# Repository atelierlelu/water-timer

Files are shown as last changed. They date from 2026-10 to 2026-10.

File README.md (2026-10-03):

# Water timer

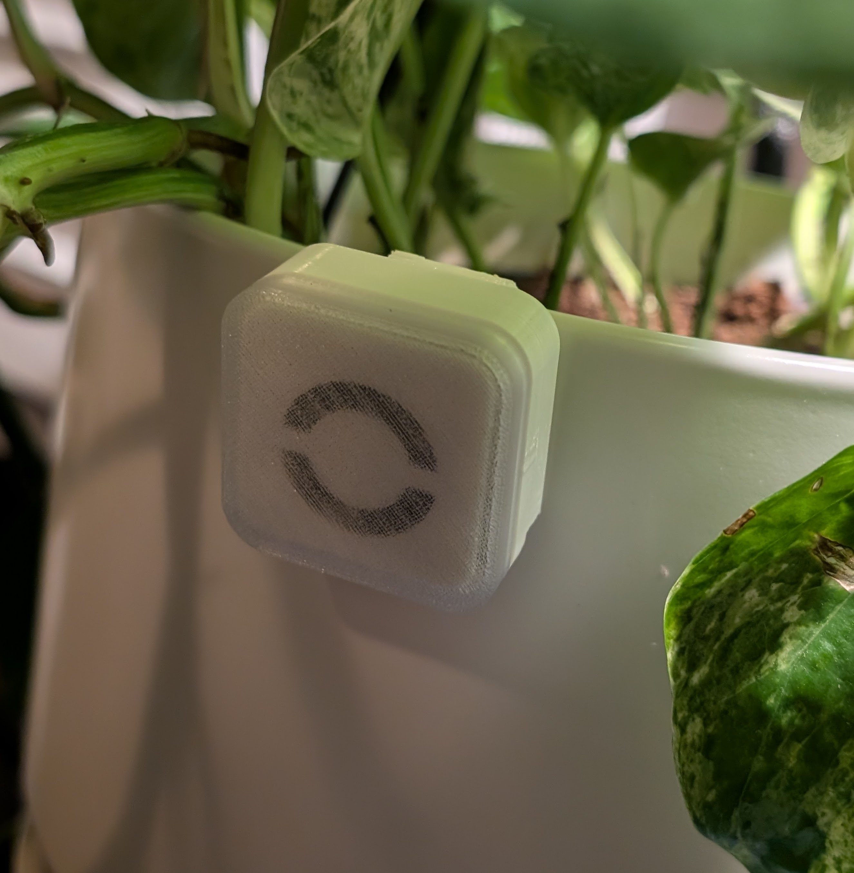
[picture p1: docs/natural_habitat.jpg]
Water timer clipped to a plant pot


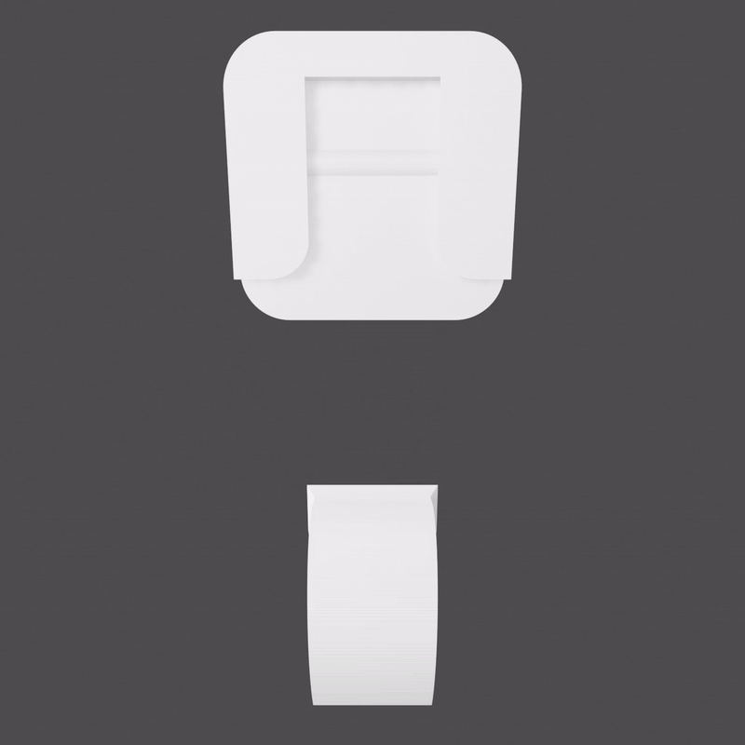
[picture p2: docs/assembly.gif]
Assembly of the water timer


CC-BY-4.0. Copyright (c) 2026 Atelier Lelu.

A small device to remind you to water a plant. Battery powered but it lasts years. That's it.

An article about the project is at <https://lelu.uk/water-timer/>.

## How to use

Once assembled, enter setup mode to configure how often it waits before blinks (1, 3 or 7 days) by long pressing the top right button for 1.5 seconds. When you release you can cycle through durations by pressing the centre button - green LEDs will blink once (for 1 day), 3 times (for 3 days) or a long blink for 7 days. It auto saves after 10 seconds.
Once the 1/3/7 days have passed, the device will blink green every minute (twice) to remind you to water the plant. Once watered press the centre button once, green LEDs flash as acknowledgement and that's it.
When the battery is low the red light will flash on button presses of when watering is due - but it should take years before you reach that point.

## In this repository

| Path | What it is |
| --- | --- |
| `enclosure/print/` | STLs to print: back, front, light mask, hook |
| `enclosure/source/` | Matching STEP files, for editing |
| `hardware/` | KiCad project, plus the JLCPCB gerbers, BOM and placement file. The schematic is [hardware/schematic.pdf](hardware/schematic.pdf) |
| `firmware/` | Plant-timer firmware, flash and test tools |
| `docs/` | Documentation |

## Make one

Print the four STLs, order the board, solder the coin-cell holder, flash the firmware, then close the case. The steps, including which jumper to close for a cell-powered timer, are in [docs/build.md](docs/build.md).

Flash before the board goes into the case. From `firmware/`:

```bash
make
make flash
```

Leave the option bytes alone. Programmer wiring and the button and LED behaviour are in [firmware/README.md](firmware/README.md).

Assembly, in order: hook, cell, board on the alignment pins, light mask, front. There are no screws. The picture is [docs/exploded.png](docs/exploded.png).

## License

Three licenses, one per kind of file. See [LICENSE.md](LICENSE.md). Hardware is CERN-OHL-P-2.0, firmware is MIT, and the documents are CC-BY-4.0. The ST files under `firmware/Drivers/` stay BSD-3-Clause.

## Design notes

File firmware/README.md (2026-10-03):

# water timer firmware (STM32L011F4, rev B)

CLI firmware for the rev B **STM32L011F4P6** board (TSSOP20). CubeMX 6.17 generated the HAL project as **EWARM only**; this tree adds a GCC `Makefile` and linker script so you can build, flash, and log from the command line.

The current image is the **plant timer** (`Core/Src/app.c`): Stop + LSI RTC, watered / view / setup on the two buttons, EEPROM interval, low-battery overlay. Waiting uses the EEPROM 1/3/7 day. How to force a one-minute due on the bench is in [Bench test](#bench-test).

## Everyday use

NRST is wired to the ST-LINK. `make flash` connects under reset, so the chip can be in Stop.

```bash
make
make flash
make picocom        # live UART on /dev/ttyACM0 (Ctrl-A Ctrl-X to quit)
```

Leave the option bytes alone. Rev B pulls BOOT0 down, so a new chip boots main flash. `make optbytes` is not part of programming this board.

A plain `st-info` while the core is in Stop can show `chipid 0x000`. That is the debug clock gated, not a dead chip. Connect under reset, or wait until the core is in Run.

The core stays in Run for **10 s after reset** with both LEDs blinking (`never_remove_swd_boot_window()` in `main.c`). **Do not remove, shorten, or move it.** It is the visible sign that the new image started, and a second way to attach if reset connect fails. After the window the plant timer starts and enters Stop.

SETUP (long-press the small button, solid red) also holds Run. The 10 s idle timer leaves SETUP and enters Stop. If a write is going without reset held, tap the big button about every 5 s until flash says verified, or a half-erased image comes back as UART garbage.

If `make flash` does not attach:

```bash
make catchflash              # retry SWD for 90 s
make catchflash CATCH_SECS=30
```

Short non-interactive capture: `make serial`. SWD RTT (`make log`) still works but halts the core; prefer UART.

## First fresh board

Factory option bytes are already the right ones. Do not run `make optbytes`.

1. Programmer first: an ST-LINK appears as `0483:374b` on USB, with UART on `/dev/ttyACM0`. Cube Programmer should show about 3.2 V. Confirm the probe is the L011 (`chipid 0x457`, 16 KiB flash), not the debugger's own MCU.
2. `make` then `make flash`. **Flash written and verified** means the image is in flash.
3. Both LEDs blink ~10 s, then go dark. UART at 115200 8N1:

```
SWD window 10s — do not strip this
EEPROM invalid: default interval_enum=1 (3 days)
water_timer L011 plant
state=WAITING elapsed_s=0 interval_s=259200 interval_enum=1 (3 days) wakeup_s=900 vdda_mv=…. low_batt=0
```

`EEPROM invalid` is normal on a new chip (empty data EEPROM → default 3-day enum). After the window the core enters Stop (`chipid 0x000` again) — that is success.

Everyday flashing after this is [Everyday use](#everyday-use). Why the option bytes stay factory is in [Boot](#boot).

## User manual

Two buttons and two LEDs. After the 10 s power-on blink (both LEDs, programming window — not a plant signal), the timer is either **waiting** (dark), **due** (green double-blink), or **setup** (solid red).

### How to read the LEDs

| What you see | Meaning |
| --- | --- |
| Both LEDs blinking together for ~10 s after battery / reset | Programming window. Ignore for plant use. |
| Dark | Waiting. Interval is running. Nothing to do. |
| One short green (right after the big button) | Watered. Timer restarted. |
| One short green (after the small button) | Current interval is **1 day**. |
| Three short greens | Current interval is **3 days**. |
| One long green (~½ s) | Current interval is **1 week**. |
| Two very brief greens, repeating every 60 s | **Due — water the plant**, then press the big button. |
| Solid red | **Setup** — you are changing the interval. Green still plays the code above. |
| Short red (with a button, or with the due blink) | Battery is low. Replace the CR2032. |

Due is always **two** shorts. One short is never “due”.

### Buttons — normal use (waiting or due)

| Button | Press | What happens |
| --- | --- | --- |
| **Big** (button 1, watered) | Short or long | “I watered.” One short green. Timer starts over. Leaves due. |
| **Small** (button 2, view) | Short (tap) | Plays the green interval code (1 day / 3 days / 1 week). |
| **Small** | Long (hold ~1.5 s) | Enter setup (red stays on). |
| Both at once | — | Ignored. |

### Buttons — setup (solid red)

Stay in setup until you leave. The green code repeats about every 2 s so you can see the current choice. Solid red also means SWD can attach — tap the big button every few seconds if you are flashing, or 10 s idle will Stop mid-write.

| Button | Press | What happens |
| --- | --- | --- |
| **Big** | Short | Cycle interval: 1 day → 3 days → 7 days → 1 day. Green plays the new code. |
| **Big** | Long | Ignored (red stays on). |
| **Small** | Short or long | Save if you changed something, then exit (red off). |
| — | 10 s with no press | Same as small: save if dirty, exit. |

A battery swap also restarts the timer (elapsed time is only in RAM). The chosen interval is kept in EEPROM.

## Hardware

| Item | Detail |
| --- | --- |
| MCU | STM32L011F4P6, Cortex-M0+, chipid `0x457` |
| Flash | 16 KiB at `0x08000000` |
| RAM | **2 KiB** at `0x20000000` (see [Memory map](#memory-map)) |
| Clock | MSI 2.097 MHz |
| RED LED | PA2 (active high) |
| GREEN LED | PA5 (active high) |
| Main button (watered) | PA6 `BUTTON_1`, active-low, external 10 kΩ + 100 nF |
| Small button (view / setup) | PA7 `BUTTON_2`, same |
| USART2 | PA9 TX / PA10 RX, 115200 8N1 |
| SWD | PA13 SWDIO / PA14 SWCLK |
| BOOT0 | PB9 / U1 pin 1. Pulled down on the board, so factory bytes boot main flash |
| NRST | Wired to the ST-LINK. `make flash` connects under reset |

Programmer is an ST-LINK/V2.1 (`0483:374b`), such as a Nucleo used as a dongle. Confirm SWD is talking to the L011 (`chipid 0x457`, 16 KiB flash), not the Nucleo’s own MCU. UART on `/dev/ttyACM0` is the L011 once the virtual COM port is wired as below.

## Host packages

```bash
sudo apt install gcc-arm-none-eabi libnewlib-arm-none-eabi stlink-tools python3 python3-serial usbutils
```

Optional: `picocom` for an interactive UART terminal. Add your user to `dialout` and `plugdev` so `st-flash` and `/dev/ttyACM0` work without root. `python3-serial` is for `tools/ppk2.py`.

Cube Programmer is the flash fallback (`STM32_Programmer_CLI` under `/opt/st/stm32cubeide_*`). Distro `st-util` is the SWD server. CubeIDE OpenOCD CLI scripts recurse here and are not usable.

## Boot

Rev B pulls PB9/BOOT0 down. Factory bytes are `nBOOT_SEL=0` (boot from the pin), `nBOOT0=0`, `nBOOT1=1`. The pulldown makes that pin read as main flash, so a new chip starts the application after `make flash`. Do not run `make optbytes`.

`make optbytes` forces `nBOOT_SEL=1`, which ignores the pin. That was a workaround for an earlier board whose BOOT0 pad floated. On this board it is unused.

| Byte | Leave it | Meaning |
| --- | --- | --- |
| `nBOOT_SEL` | 0 | BOOT0 comes from PB9 |
| `nBOOT0` | 0 | Unused while `nBOOT_SEL` is 0 |
| `nBOOT1` | 1 | Keep (0 boots empty SRAM) |
| RDP | `0xAA` | Level 0, no readout protection |

**Do not** set RDP, set `nBOOT1=0`, remap PA13/PA14, or switch the app to Standby. Those cut off SWD programming.

## UART (ST-LINK VCP)

USART2 is 115200 8N1 on **PA9 TX / PA10 RX**. `/dev/ttyACM0` is that port after the Nucleo VCP is pointed at the L011.

CN3 silkscreen is the **ST-LINK** side. UART is crossed; same-name to same-name is wrong (two TXes fight):

| L011 | Nucleo |
| --- | --- |
| PA9 `USART2_TX` | CN3 **RX** |
| PA10 `USART2_RX` | CN3 **TX** |
| GND | GND |

A stock Nucleo-64 has **SB13 and SB14 ON**, so the onboard MCU already owns the virtual COM port. Lift those bridges before using that port for the L011. Do not put L011 TX on that net while they are still fitted.

```bash
make picocom                 # interactive
make serial                  # SECONDS=8 dump
make serial SECONDS=3        # shorter
```

Expected text after a power-cycle:

```
SWD window 10s — do not strip this
water_timer L011 plant
state=WAITING elapsed_s=0 interval_s=259200 interval_enum=1 (3 days) wakeup_s=900 vdda_mv=…. low_batt=0
```

Button presses print `button 1 (main / watered): short` or `button 2 (small / view): long` (or `none` on a bounce). Setup prints enter / heartbeat / cycle / exit-reason / EEPROM lines so a hang is visible.

## Bench test

Do not wait a real day to see DUE. Waiting becomes due when `elapsed_s` reaches `interval_s`. On a plant that is 86400 / 259200 / 604800. Two ways to make `interval_s` 60 so DUE happens in about a minute. UART still prints the EEPROM name (`interval_enum=2 (7 days)`); watch `interval_s`, not that string.

**Preferred: both buttons at the end of the 10 s blink.** No rebuild. After reset both LEDs blink for 10 s (`never_remove_swd_boot_window`) — the plant timer has not started yet. When that blink **ends**, `app_init()` reads EEPROM and samples the buttons once. If **both** are held at that instant:

```
boot: both buttons held, test interval until SETUP save
state=WAITING elapsed_s=0 interval_s=60 interval_enum=… wakeup_s=10
```

RTC then wakes every 10 s; DUE at ~60 s. The EEPROM enum is unchanged (RAM flag `g_test_until_save`). It stays on 60 s until a SETUP save that actually writes EEPROM (cycle the interval so dirty, then exit). Opening SETUP and leaving without a change does not clear it. Reset or a battery pull clears it unless you hold both again.

Hold through the **end** of the blink, not only the start. During normal waiting, both buttons together are ignored; this check is boot-only.

**Compile-time override.** If `APP_TEST_INTERVAL_S` in `app.c` is non-zero, **every** boot uses that many seconds and never looks at EEPROM or the both-buttons flag. That is how you get `interval_enum=2 (7 days)` with `interval_s=60` and SETUP cannot change the wait. It is **0** in the tree (real days). Set it to `60`, `make flash`, and set it back to `0` before a plant image.

## Board bring-up

Factory check for a new board, fed from the PPK2 with the solder bridges open and the ST-LINK 3V3 jumper off. What the image checks is in [board_bringup.md](board_bringup.md). The script appends a local `board_tests.csv`; that log is not part of this tree.

```bash
make flash-boardtest          # connects under reset; PPK2 on
python3 tools/board_test.py   # prompts, then flashes the plant image
```

The test image (`Core/Src/board_test.c`) stays in Run. It checks both buttons (green = big, red = small, both LEDs = both), EEPROM, 60 s of RTC drift, and the 2400/2500 mV low-battery thresholds on the chip's own VDDA. Move only on a `NOW` line. After the buttons, leave it alone.

A passing board is then flashed with the plant timer. The measured LSI error is compiled in as `APP_RTC_SYNCH_PREDIV` (nominal 288). A plain `make flash` does **not** carry that correction, and `build/firmware.bin` after a batch is only the last board. Run the script per chip.

The EEPROM check erases the stored interval, so the plant image boots at the 3-day default. Stop-current columns in the CSV are the PPK2 floor while the ST-LINK is attached. They are not a reject limit.

## RTT logs

The default image writes a small SEGGER-compatible ring buffer in SRAM (no `BKPT`). The core keeps running if nobody is listening.

```bash
make log                 # until Ctrl-C
make log LOG_SECONDS=8   # short capture
```

`tools/swd_rtt.py` starts `st-util --no-reset`, finds `"SEGGER RTT"` in SRAM, and polls the up-buffer. Same strings as UART. `st-util` does not speak RTT itself; the Python poller does. No extra host packages.

`st-util` cannot read SRAM while the core runs, so `make log` **halts every ~150 ms**. SysTick freezes during those halts. UART does not do that — prefer `make picocom` for everyday text. `make log` also needs SWD, so use it during the 10 s boot window or while SETUP is holding Run (long-press the small button).

## Other targets

```bash
make              # plant-timer ELF/BIN/HEX (RTT on, no BKPT)
make flash        # program over SWD, connecting under reset
make catchflash   # retry SWD for CATCH_SECS (default 90)
make probe        # list ST-LINK devices
make log          # attach SWD and stream RTT (no reset)
make swdlog       # optional semihosting build + ~8 s of BKPT text
make run          # same, keep SWD attached
make serial       # dump L011 UART from PORT=/dev/ttyACM0 for SECONDS
make picocom      # interactive L011 UART on that port
make clean
make help
python3 tools/ppk2.py probe          # PPK2 port check; does not power the board
python3 tools/ppk2.py capture --mv 3300 --seconds 15
```

### If SWD is wedged

Stop gates the debug clock. `st-info` may show the dongle but `flash: 0` / `chipid: 0x000`, or `st-flash` may report `Failed to enter SWD`. That is expected while sleeping. Do **not** treat it as a dead chip.

1. **Best:** `make flash`. It connects under reset. NRST is on the ST-LINK, so Stop does not block the write.
2. If reset connect fails: long-press the small button (solid red) and tap the big button so SETUP does not idle-exit, then `make flash` again. Or power-cycle and flash during the 10 s blink.
3. Or `make catchflash`.
4. If the probe itself is stuck: kill leftover `st-util`, then reset USB and retry:

```bash
pkill st-util || true
usbreset 0483:374b
st-info --probe          # expect chipid 0x457, 16 KiB flash — only if the core is in Run
```

## UART vs SWD text

The plant timer writes the same strings to USART2 and to RTT. Use UART (`make picocom`) as the normal console. RTT is the fallback when you only have SWD. Optional `make run` / `make swdlog` also emit ARM semihosting (`BKPT 0xAB`); that image hangs if no debugger is attached, so it is not the default.

## Why `main` fixes VTOR and PRIMASK

A debugger jump (or leaving the ROM loader) can leave leftover state:

- **VTOR** still points at system memory. The first SysTick then vectors into ROM. `main` sets `SCB->VTOR = FLASH_BASE`.
- **PRIMASK** can be set, so SysTick never ticks and `HAL_Delay` hangs. `main` calls `__enable_irq()`.

## Memory map

The linker script (`STM32L011F4Px_FLASH.ld`) is **16 KiB flash / 2 KiB RAM**, heap 0, stack `0x400`. `st-info` sometimes reports 8 KiB SRAM (tool table for the L0 category). Trust the datasheet and the linker, not that SRAM number. The RTT up-buffer is 128 bytes.

## Layout

| Path | Role |
| --- | --- |
| `firmware.ioc` | CubeMX 6.17 project (do not regenerate over the GCC files) |
| `Makefile` | GCC build, flash under reset, RTT log |
| `STM32L011F4Px_FLASH.ld` | 16K/2K memory map |
| `Core/Src/main.c` | Clocks, UART, Stop, **10 s SWD boot window** (do not strip) |
| `Core/Src/app.c` | Plant-timer FSM, LEDs, buttons, EEPROM, VREFINT |
| `Core/Src/rtt_log.c` | SEGGER-compatible RTT up-buffer |
| `Core/Src/swd_log.c` | ARM semihosting, compiled in only with `-DSWD_SEMIHOSTING` |
| `tools/swd_rtt.py` | `st-util` client: hotplug and stream RTT |
| `tools/swd_semihost.py` | Optional BKPT semihosting client |
| `tools/ppk2.py` | PPK2 source-mode capture |
| `tools/board_test.py` | Bring-up script: buttons, RTC, low-battery, then plant flash |
| `Core/Src/board_test.c` | Bring-up image (separate from the plant timer) |
| `board_bringup.md` | What the bring-up image checks |

Startup is the CMSIS GCC template `startup_stm32l011xx.s`.

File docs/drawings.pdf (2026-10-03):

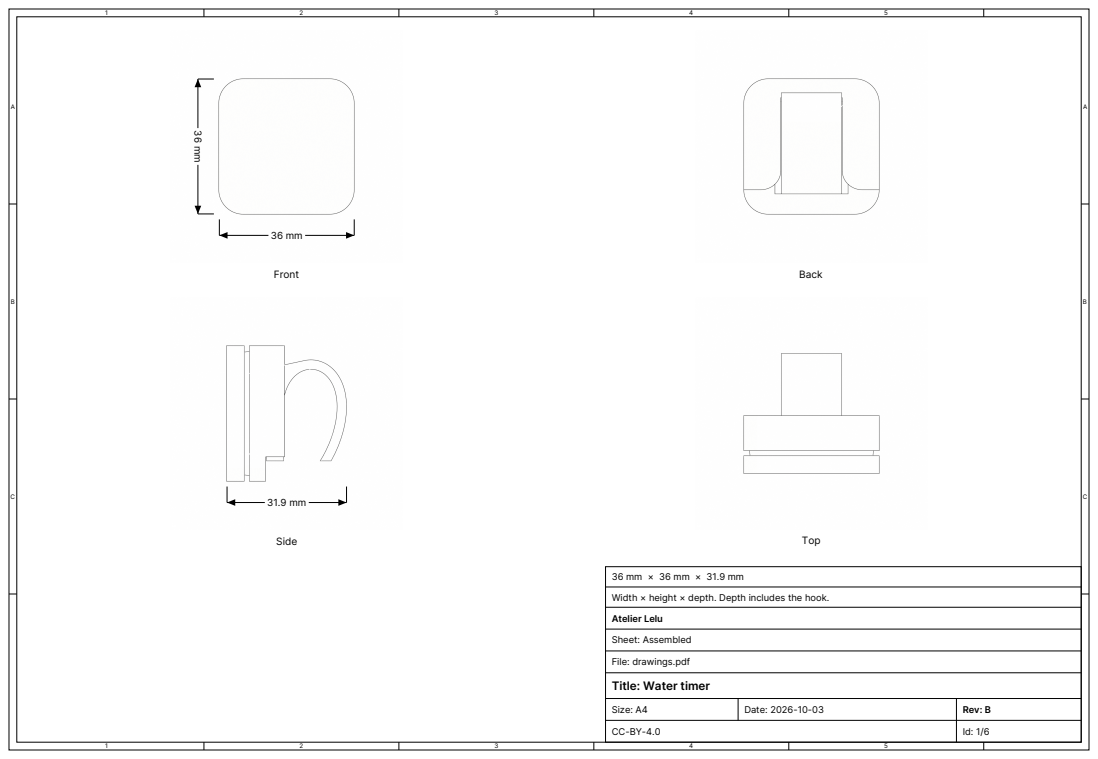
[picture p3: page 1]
Size: A4; Date: 2026-10-03; Rev: B; Sheet: Assembled; Atelier Lelu; Front; Back; Side; Top

Width × height × depth. Depth includes the hook.

File: drawings.pdf
Title: Water timer

A | A
B | B
C | C
Size: A4 | Date: 2026-10-03 | Rev: B

## Title: Water timer

File: drawings.pdf

Sheet: Case back

Atelier Lelu

Front | Back
Side | Top

A | A
B | B
C | C
Size: A4 | Date: 2026-10-03 | Rev: B

## Title: Water timer

File: drawings.pdf

Sheet: Case front

Atelier Lelu

Front | Back
Side | Top

A | A
B | B
C | C
Size: A4 | Date: 2026-10-03 | Rev: B

## Title: Water timer

File: drawings.pdf

Sheet: Light mask

Atelier Lelu

Front | Back
Side | Top

A | A
B | B
C | C
Size: A4 | Date: 2026-10-03 | Rev: B

## Title: Water timer

File: drawings.pdf

Sheet: Slide-in hook

Atelier Lelu

Front | Back
Side | Top

A | A
B | B
C | C
Size: A4 | Date: 2026-10-03 | Rev: B

## Title: Water timer

File: drawings.pdf

Sheet: Board

Atelier Lelu

Front | Back
Side | Top

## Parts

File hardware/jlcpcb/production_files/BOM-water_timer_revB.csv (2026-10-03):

Comment | Designator | Footprint | LCSC | Quantity
0.1u | C1,C2,C4,C5,C6 | C_0402_1005Metric | C1525 | 5
10k | R1,R2,R3,R4,R5,R6,R7 | R_0402_1005Metric | C25744 | 7
10u | C3 | C_0402_1005Metric | C15525 | 1
D_Schottky | D4,D5 | D_SOD-123 | C7420332 | 2
Green | D1,D2 | LED_0805_2012Metric | C2297 | 2
Red | D3 | LED_0805_2012Metric | C84256 | 1
STM32L011F4Px | U1 | TSSOP-20_4.4x6.5mm_P0.65mm | C503083 | 1
SW_Push | SW1,SW2 | TS-1187A-B-A-B SPST switch | C318884 | 2

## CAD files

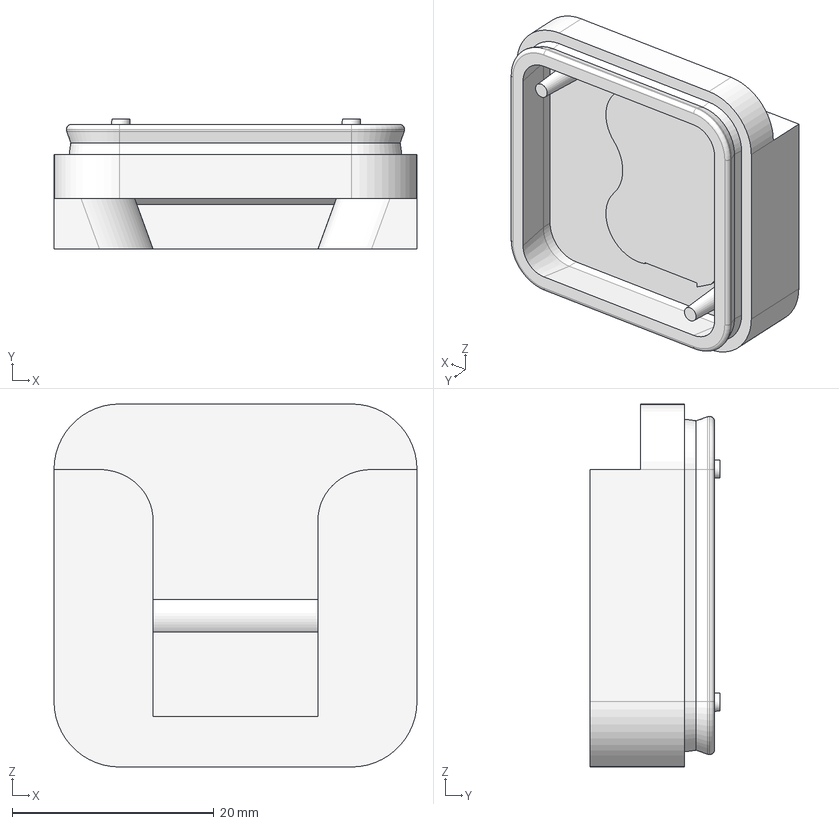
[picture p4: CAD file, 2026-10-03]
enclosure/source/case_back.step
36.0 x 12.9 x 36.0 mm

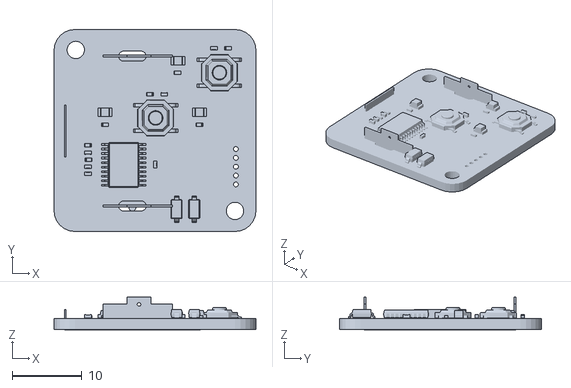
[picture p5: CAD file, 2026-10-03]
hardware/water_timer_revB.stl
29.0 x 29.0 x 4.70

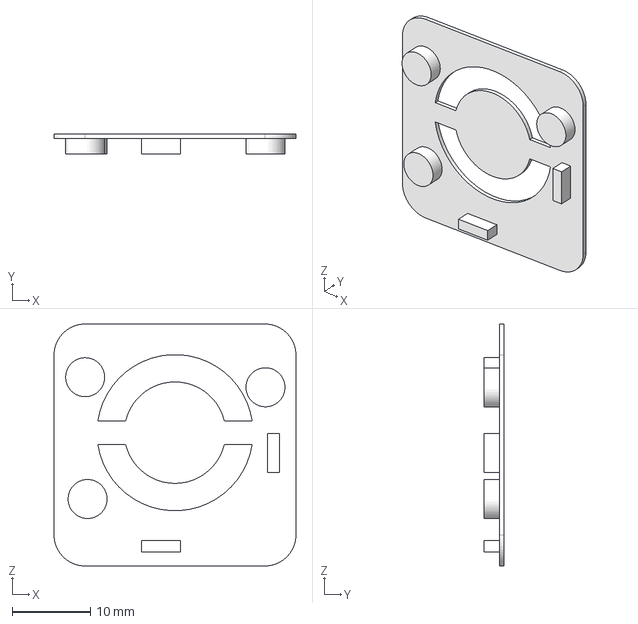
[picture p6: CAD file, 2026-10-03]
enclosure/source/light_mask.step
31.0 x 2.60 x 31.0 mm

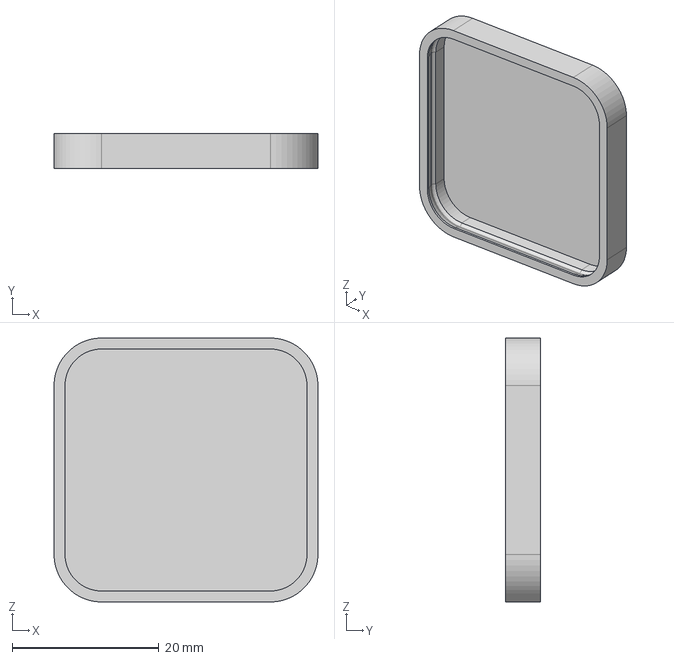
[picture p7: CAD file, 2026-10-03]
enclosure/source/case_front.step
36.0 x 4.72 x 36.0 mm

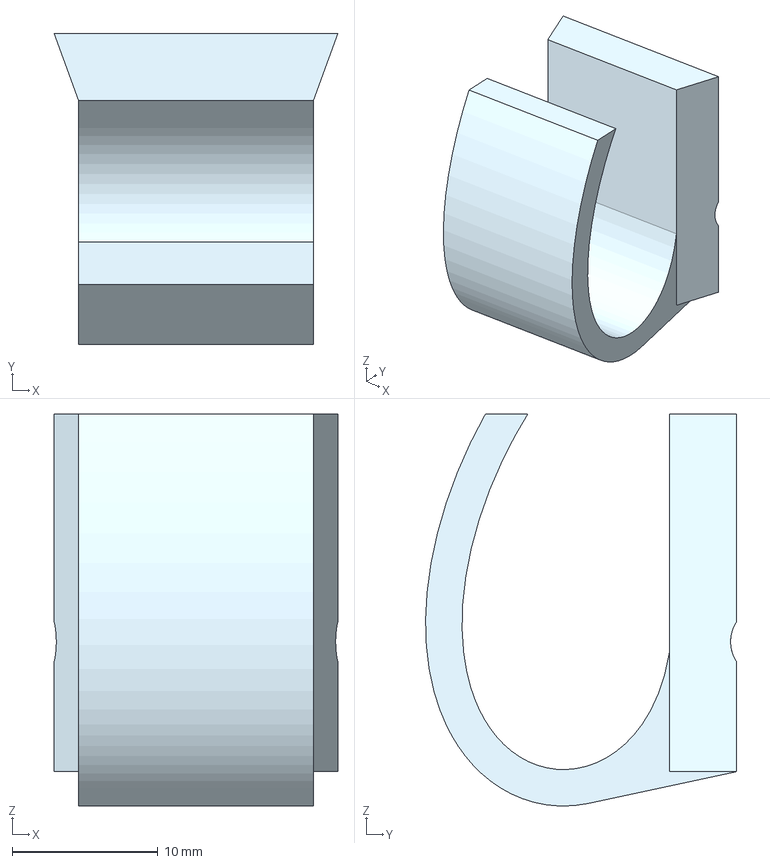
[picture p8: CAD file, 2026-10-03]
enclosure/source/slide_in_hook.step
19.4 x 21.3 x 26.8 mm

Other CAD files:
enclosure/print/case_back.stl
enclosure/print/case_front.stl
enclosure/print/light_mask.stl
enclosure/print/slide_in_hook.stl

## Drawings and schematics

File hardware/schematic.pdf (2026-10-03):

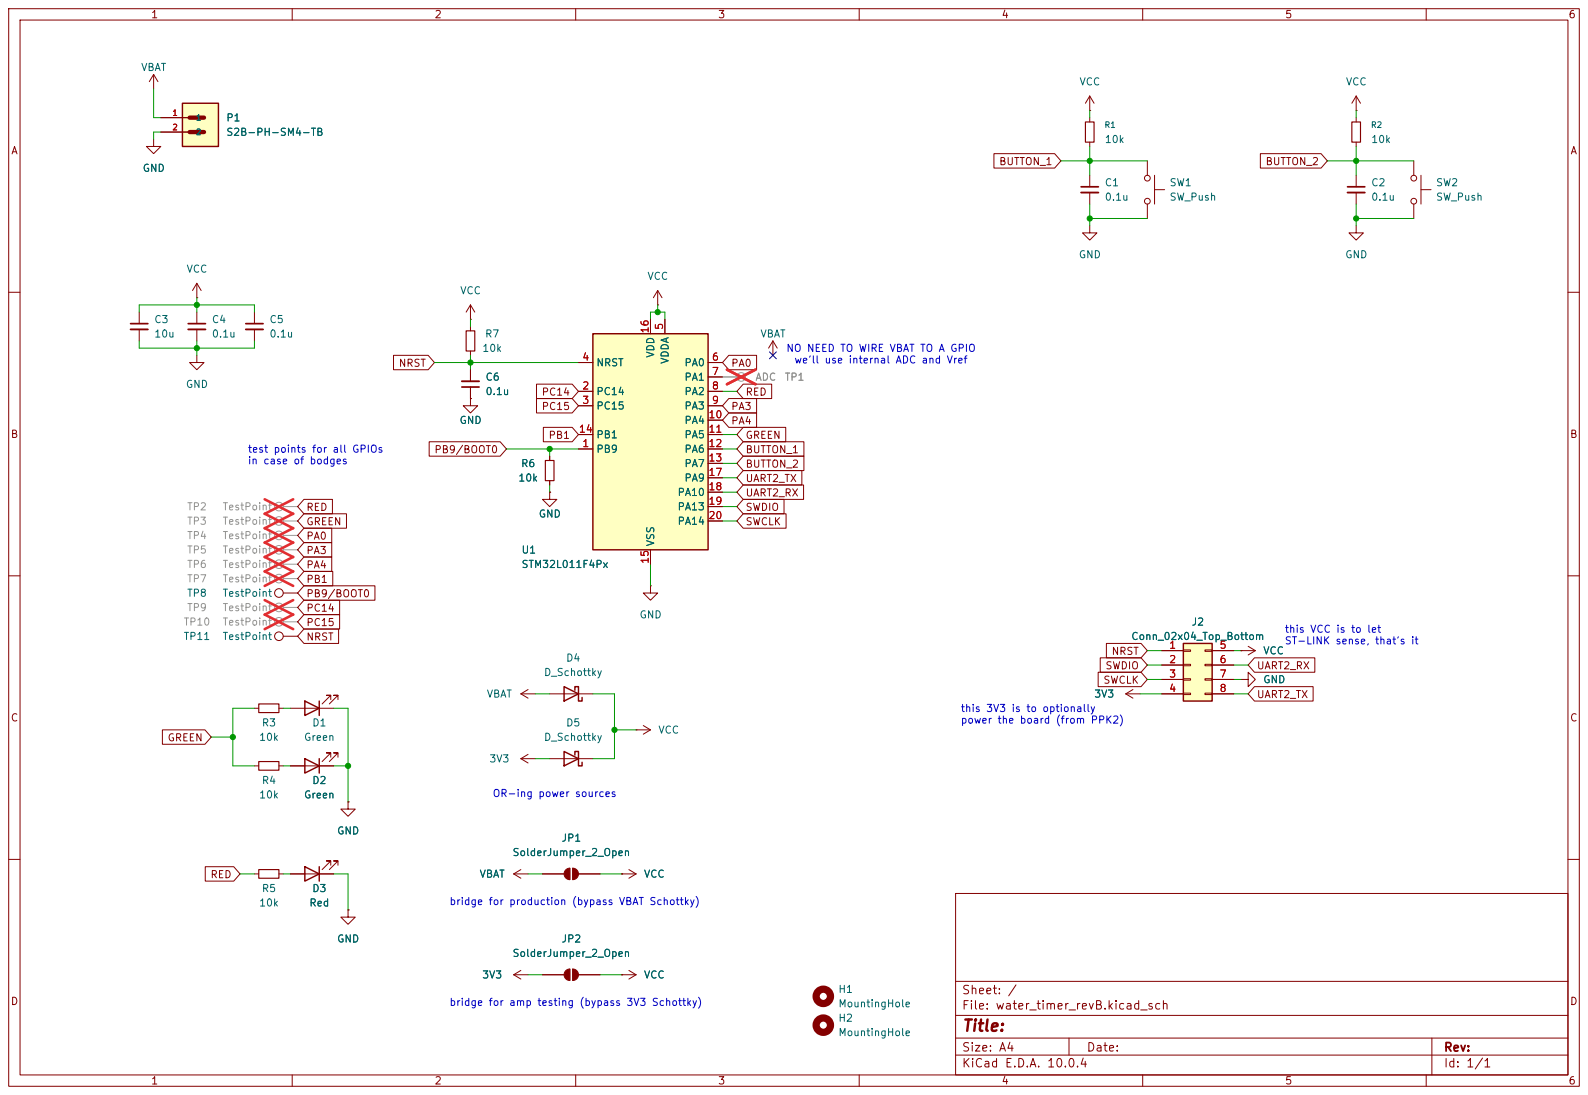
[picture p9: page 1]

NO NEED TO WIRE VBAT TO A GPIO
we'll use internal ADC and Vref

test points for all GPIOs

this VCC is to let ST-LINK sense, that's it bridge for production (bypass VBAT Schottky)

this 3V3 is to optionally power the board (from PPK2)

OR-ing power sources

bridge for amp testing (bypass 3V3 Schottky)

Size: A4 | Rev:
KiCad E.D.A. 10.0.4 | Id: 1/1

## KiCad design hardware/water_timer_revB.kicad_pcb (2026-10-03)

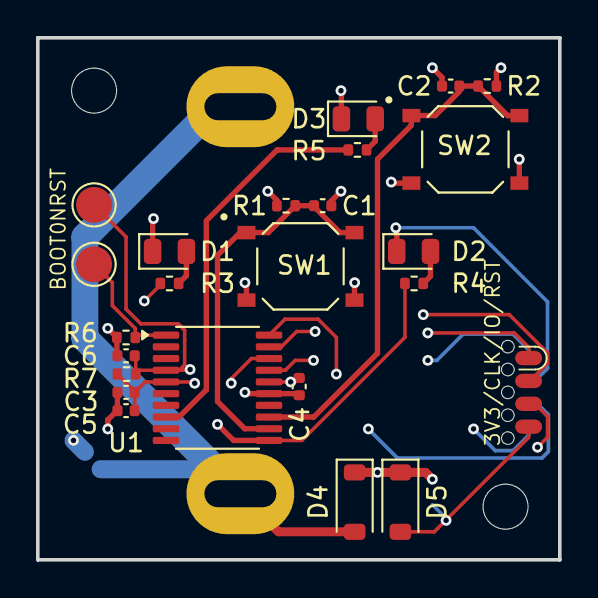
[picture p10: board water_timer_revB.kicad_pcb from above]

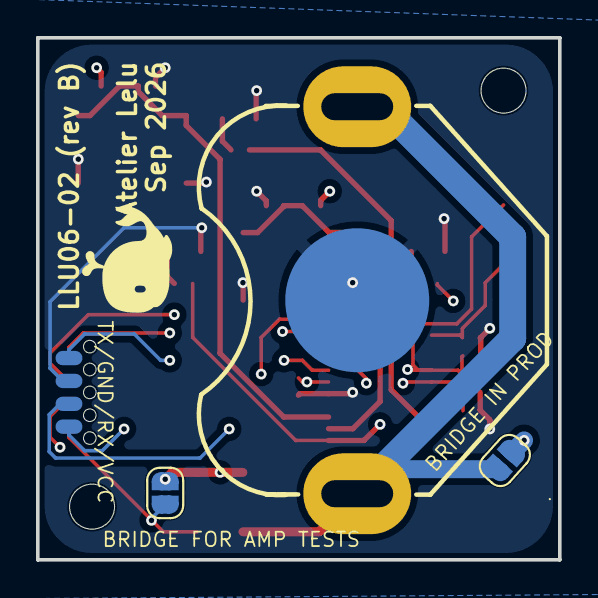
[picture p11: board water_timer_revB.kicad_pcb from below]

Board: 4 copper layers, 29.0 x 29.0 mm, 29 parts (3 on the bottom side), 17 nets.

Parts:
C1, C2, C4, C5, C6: 0.1u; C_0402_1005Metric
C3: 10u; C_0402_1005Metric
D1, D2: Green; LED_0805_2012Metric
D3: Red; LED_0805_2012Metric
D4, D5: D_Schottky; D_SOD-123
H1, H2: MountingHole; MountingHole_2.5mm
J2: Conn_02x04_Top_Bottom; SOIC_clipProgSmall
JP1, JP2: SolderJumper_2_Open; SolderJumper-2_P1.3mm_Open_RoundedPad1.0x1.5mm
P1: S2B-PH-SM4-TB; BAT-TH_MY-2032-22
R1, R2, R3, R4, R5, R6, R7: 10k; R_0402_1005Metric
SW1, SW2: SW_Push; TS-1187A-B-A-B SPST switch
TP8, TP11: TestPoint; TestPoint_Pad_D2.0mm
U1: STM32L011F4Px; TSSOP-20_4.4x6.5mm_P0.65mm

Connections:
3V3: D5.2 (A), J2.4, JP2.1 (A)
BUTTON_1: C1.1, R1.2, SW1.1, U1.12 (PA6)
BUTTON_2: C2.1, R2.2, SW2.1, U1.13 (PA7)
GND: C1.2, C2.2, C3.2, C4.2, C5.2, C6.1, D1.1 (K), D2.1 (K), D3.1 (K), J2.7, P1.2, R6.1, SW1.2, SW2.2, U1.15 (VSS)
GREEN: R3.1, R4.1, U1.11 (PA5)
NRST: C6.2, J2.1, R7.1, TP11.1 (1_1), U1.4 (NRST)
unnamed: D1.2 (A), R3.2
unnamed: D2.2 (A), R4.2
unnamed: D3.2 (A), R5.2
PB9/BOOT0: R6.2, TP8.1 (1_1), U1.1 (PB9)
RED: R5.1, U1.8 (PA2)
SWCLK: J2.3, U1.20 (PA14)
SWDIO: J2.2, U1.19 (PA13)
UART2_RX: J2.6, U1.18 (PA10)
UART2_TX: J2.8, U1.17 (PA9)
VBAT: D4.2 (A), JP1.1 (A), P1.1
VCC: C3.1, C4.1, C5.1, D4.1 (K), D5.1 (K), J2.5, JP1.2 (B), JP2.2 (B), R1.1, R2.1, R7.2, U1.5 (VDDA), U1.16 (VDD)

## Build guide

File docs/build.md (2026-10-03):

# Build

CC-BY-4.0. Copyright (c) 2026 Atelier Lelu.

The water timer is made of a printed case, a PCB, a coin-cell holder you solder yourself, a CR2032, and the firmware in `firmware/`.

## Print

0.2 mm layers, 0.4 mm nozzle. Back, light mask, and hook in white PETG. PLA is fine for those three. The front is translucent PETG.

| File | Part |
| --- | --- |
| `enclosure/print/case_back.stl` | Back with alignment pins |
| `enclosure/print/case_front.stl` | Front cover (translucent) |
| `enclosure/print/light_mask.stl` | Mask over the LEDs |
| `enclosure/print/slide_in_hook.stl` | Hook that slides into the back |

The matching STEP files in `enclosure/source/` are the ones to edit.

## Board

Order from `hardware/jlcpcb/production_files/`:

- `GERBER-water_timer_revB.zip`
- `BOM-water_timer_revB.csv`
- `CPL-water_timer_revB.csv`

The KiCad project is `hardware/water_timer_revB.kicad_pro`.

The JLCPCB BOM does not include the coin-cell holder. Solder one yourself on `P1`. The schematic symbol on that reference is a connector; the footprint on the board is `BAT-TH_MY-2032-22`. Fit a CR2032 in that holder.

Two solder jumpers ship open:

| Jumper | Close it when |
| --- | --- |
| `JP1` | The timer runs from the coin cell. This bypasses the cell's Schottky |
| `JP2` | Leave open |

## Flash

I am using a custom SOIC-8 mousebite connector to connect to my ST-LINK. 
Flash the board before it goes into the case. From `firmware/`:

```bash
make
make flash
```

NRST is wired to the ST-LINK, so `make flash` connects under reset. Leave the option bytes alone. Details, UART wiring, and the bring-up image are in `firmware/README.md`.

## Case

1. Slide the hook into the back
2. Put the CR2032 in the holder
3. Sit the board on the alignment pins
4. Place the light mask over the LEDs
5. Close the front (snap fit)

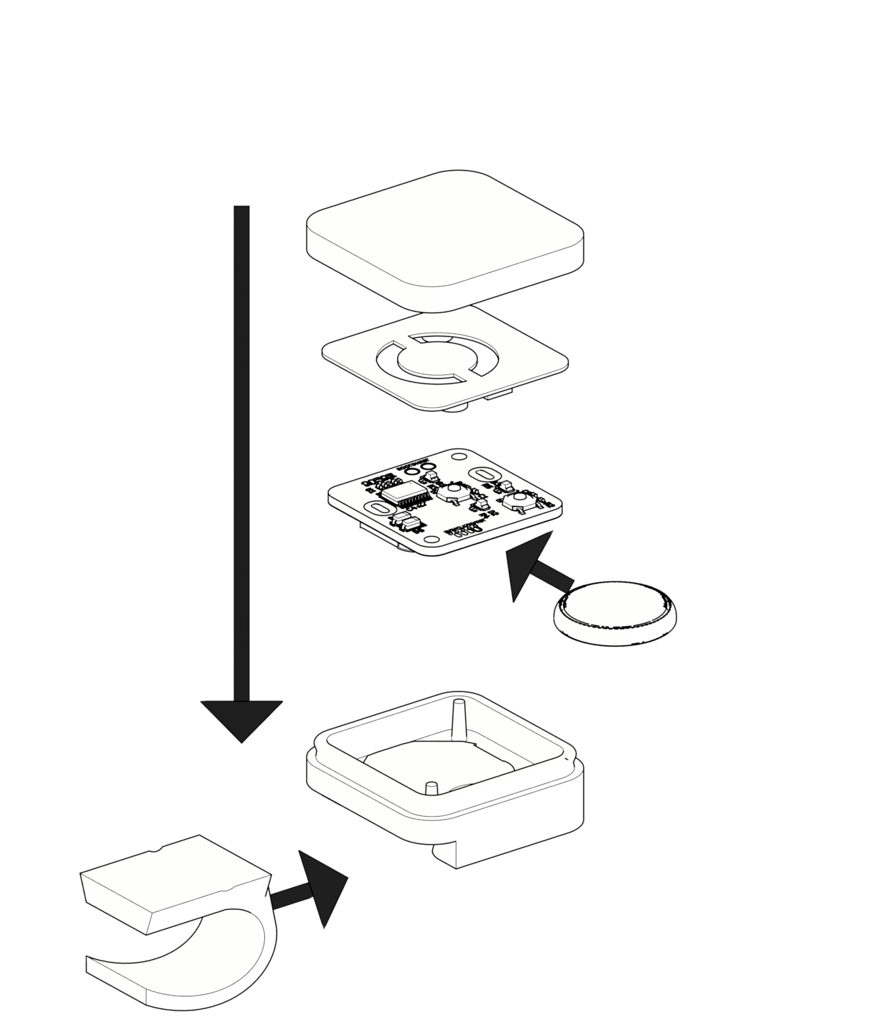
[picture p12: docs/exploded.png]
Assembly: hook and coin cell slide in, the other parts stack


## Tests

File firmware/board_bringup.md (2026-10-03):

# Board bring-up, 27 Sep 2026

Rev B boards were tested on the bench and then programmed with the plant timer. How to run the next one is in [README.md](README.md#board-bring-up).

The PPK2 fed the board through the unbridged solder bridges (Schottky diodes in series). The ST-LINK stayed connected for SWD and UART. Its 3V3 jumper stayed off, so the rail followed the PPK2. At run current the drop was about 220 mV (PPK2 at 3300 mV, chip near 3080 mV).

## What the script does

`python3 tools/board_test.py` powers the board at 3300 mV and walks one image (`make flash-boardtest`, `Core/Src/board_test.c`). That image stays in Run. The plant timer is a separate build and is flashed only after the checks pass.

1. Both LEDs blink for the 10 s programming window, then red, green, and both.
2. Operator, on a `NOW` line: hold the big button (green), the small button (red), then both (both LEDs).
3. EEPROM: write, read, and erase a test word. This wipes the stored plant interval. A new plant image therefore boots at the 3-day default.
4. RTC: 60 seconds of the LSI calendar against the host clock. The test image uses the nominal dividers, async 127 and sync 288.
5. Low battery: step the PPK2 down until the chip reports `low_batt` at or below 2400 mV, then back up. Clear counts only once the chip is again at or above 2500 mV, so a sample that settles inside the hysteresis band does not fail the board.
6. Stop current at PPK2 3200, 3000, 2800, and 2600 mV. The chip sleeps 8 s at each step. The script records the median.
7. If buttons, EEPROM, RTC, and low-battery passed, rebuild the plant image with a corrected sync prescaler and `st-flash` it while the PPK2 is still on. The row is appended either way.

RTC pass limit in the script is ±20%. The plant budget in the spec is about ±10%. Two boards were outside ±10% and still inside ±20%, and they were flashed.

## RTC correction

Drift is `(RTC seconds / wall seconds − 1) × 100`, measured with dividers 127 / 288. A positive number means the LSI ran fast.

The flashed sync prescaler is `round((1 + drift/100) × 289) − 1`. Async stays 127. That puts `ck_spre` on 1 Hz for the measured LSI. `HAL_RTC_Init` writes the prescaler only while the calendar is blank, and the backup domain keeps the old divider across reset, so `rtc_apply_prescaler()` in `main.c` writes it on every boot.

`make flash` with no extra flags still builds the nominal 288. The corrected value is compiled into that board's image only. The binary left in `build/` after a batch is the last board's image. Do not copy it onto another chip. Run the script, which rebuilds from that board's own drift.

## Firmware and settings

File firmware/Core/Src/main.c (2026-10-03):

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
/* Includes ------------------------------------------------------------------*/
#include "main.h"

/* USER CODE BEGIN Includes */
#include <stdint.h>
#include "app.h"
#include "rtt_log.h"
#include "swd_log.h"
#ifdef BOARD_TEST
#include "board_test.h"
#endif
/* USER CODE END Includes */

/* USER CODE BEGIN PD */
/**
 * LSI is ~37 kHz (LSI_VALUE). 37000 / ((127+1)*(288+1)) ≈ 1 Hz ck_spre.
 * The board test passes -DAPP_RTC_SYNCH_PREDIV when it flashes a measured board,
 * so this nominal pair stays the uncalibrated default.
 */
#ifndef APP_RTC_ASYNCH_PREDIV
#define APP_RTC_ASYNCH_PREDIV   127U
#endif
#ifndef APP_RTC_SYNCH_PREDIV
#define APP_RTC_SYNCH_PREDIV    288U
#endif
/** Dummy calendar start; the wall date does not matter. */
#define APP_RTC_YEAR            26U
#define APP_RTC_MONTH           1U
#define APP_RTC_DATE            1U
/** Blocking UART timeout; a short line at 115200 finishes well under this. */
#define UART_TIMEOUT_MS         100U
/* USER CODE END PD */

UART_HandleTypeDef huart2;

/* USER CODE BEGIN PV */
RTC_HandleTypeDef hrtc;
/* USER CODE END PV */

void SystemClock_Config(void);
static void MX_GPIO_Init(void);
static void MX_USART2_UART_Init(void);
/* USER CODE BEGIN PFP */
static void MX_RTC_Init(void);
static void rtc_apply_prescaler(void);
static void uart_write(const uint8_t *data, uint16_t len);
#ifndef BOARD_TEST
static void enter_stop(void);
#endif
static void never_remove_swd_boot_window(void);
/* USER CODE END PFP */

/* USER CODE BEGIN 0 */
/**
 * Send a raw buffer over USART2 (Nucleo ST-Link VCP).
 */
static void uart_write(const uint8_t *data, uint16_t len)
{
  (void)HAL_UART_Transmit(&huart2, (uint8_t *)data, len, UART_TIMEOUT_MS);
}

/**
 * Write the same buffer to USART2, RTT, and optional semihosting.
 */
void log_write(const uint8_t *data, uint16_t len)
{
  uart_write(data, len);
  rtt_write(data, len);
  swd_write(data, len);
}

/**
 * Write a NUL-terminated string to every log sink.
 */
void log_print(const char *s)
{
  const char *p = s;

  while (*p != '\0')
  {
    p++;
  }
  log_write((const uint8_t *)s, (uint16_t)(p - s));
}

/*
 * ***************************************************************************
 * DO NOT REMOVE, DISABLE, SHORTEN, OR MOVE THIS FUNCTION.
 * DO NOT CALL enter_stop() OR ANY OTHER SLEEP FROM HERE.
 *
 * After reset the core stays in Run for 10 s so SWD can attach. Stop gates
 * the debug clock; without this window a power-cycle + make flash fails.
 * Both LEDs blink so you can see the window is open.
 * ***************************************************************************
 */
static void never_remove_swd_boot_window(void)
{
  uint32_t elapsed_ms = 0U;

  /* NEVER TOUCH: 10 s Run, no Stop, no RTC arm yet. */
  log_print("SWD window 10s — do not strip this\r\n");
  while (elapsed_ms < 10000U)
  {
    HAL_GPIO_WritePin(GPIOA, RED_Pin | GREEN_Pin, GPIO_PIN_SET);
    HAL_Delay(200U);
    HAL_GPIO_WritePin(GPIOA, RED_Pin | GREEN_Pin, GPIO_PIN_RESET);
    HAL_Delay(200U);
    elapsed_ms += 400U;
  }
}

#ifndef BOARD_TEST
/**
 * Enter Stop. RTC wakeup and button EXTI bring us back.
 * Clear leftover EXTI so Stop does not return immediately.
 * Leave DBG_STOP clear so Stop can gate the debug clock.
 * ULP turns VREFINT off in Stop. HAL_PWR_EnterSTOPMode does not set it,
 * and without it this board sat at about 13 µA instead of under 1 µA.
 */
static void enter_stop(void)
{
  __HAL_PWR_CLEAR_FLAG(PWR_FLAG_WU);
  __HAL_GPIO_EXTI_CLEAR_IT(BUTTON_1_Pin | BUTTON_2_Pin);
  HAL_DBGMCU_DisableDBGStopMode();
  HAL_PWREx_EnableUltraLowPower();
  HAL_SuspendTick();
  HAL_PWR_EnterSTOPMode(PWR_LOWPOWERREGULATOR_ON, PWR_STOPENTRY_WFI);
  HAL_ResumeTick();
  SystemClock_Config();
}
#endif

/**
 * Write the RTC prescalers on every boot.
 * HAL_RTC_Init programs them only while the calendar is still blank, and the
 * backup domain keeps the old divider across reset. The board test measures
 * drift against 127/288, then flashes a corrected synchronous divider, so
 * that value has to be applied even when the RTC is already running.
 */
static void rtc_apply_prescaler(void)
{
  __HAL_RTC_WRITEPROTECTION_DISABLE(&hrtc);
  if (RTC_EnterInitMode(&hrtc) != HAL_OK)
  {
    Error_Handler();
  }
  hrtc.Instance->PRER = (uint32_t)hrtc.Init.SynchPrediv;
  hrtc.Instance->PRER |= (uint32_t)(hrtc.Init.AsynchPrediv << RTC_PRER_PREDIV_A_Pos);
  if (RTC_ExitInitMode(&hrtc) != HAL_OK)
  {
    Error_Handler();
  }
  __HAL_RTC_WRITEPROTECTION_ENABLE(&hrtc);
}

/**
 * Start LSI-clocked RTC and load a dummy calendar. Wakeup is armed in app_init().
 */
static void MX_RTC_Init(void)
{
  RTC_TimeTypeDef time = {0};
  RTC_DateTypeDef date = {0};

  hrtc.Instance = RTC;
  hrtc.Init.HourFormat = RTC_HOURFORMAT_24;
  hrtc.Init.AsynchPrediv = APP_RTC_ASYNCH_PREDIV;
  hrtc.Init.SynchPrediv = APP_RTC_SYNCH_PREDIV;
  hrtc.Init.OutPut = RTC_OUTPUT_DISABLE;
  hrtc.Init.OutPutRemap = RTC_OUTPUT_REMAP_NONE;
  hrtc.Init.OutPutPolarity = RTC_OUTPUT_POLARITY_HIGH;
  hrtc.Init.OutPutType = RTC_OUTPUT_TYPE_OPENDRAIN;
  if (HAL_RTC_Init(&hrtc) != HAL_OK)
  {
    Error_Handler();
  }
  rtc_apply_prescaler();

  /* Reload a known start so each reset shows the calendar advancing. */
  time.Hours = 0U;
  time.Minutes = 0U;
  time.Seconds = 0U;
  time.TimeFormat = RTC_HOURFORMAT12_AM;
  time.DayLightSaving = RTC_DAYLIGHTSAVING_NONE;
  time.StoreOperation = RTC_STOREOPERATION_RESET;
  if (HAL_RTC_SetTime(&hrtc, &time, RTC_FORMAT_BIN) != HAL_OK)
  {
    Error_Handler();
  }

  date.WeekDay = RTC_WEEKDAY_THURSDAY;
  date.Month = APP_RTC_MONTH;
  date.Date = APP_RTC_DATE;
  date.Year = APP_RTC_YEAR;
  if (HAL_RTC_SetDate(&hrtc, &date, RTC_FORMAT_BIN) != HAL_OK)
  {
    Error_Handler();
  }

}

/* USER CODE END 0 */

/**
  * @brief  The application entry point.
  * @retval int
  */
int main(void)
{

  /* USER CODE BEGIN 1 */
  /* Bootloader leave VTOR at system memory; SysTick must use the flash table. */
  SCB->VTOR = FLASH_BASE;
  /* Debugger attach can leave PRIMASK set; SysTick must run for HAL_Delay. */
  __enable_irq();
  /* USER CODE END 1 */

  /* MCU Configuration--------------------------------------------------------*/

  /* Reset of all peripherals, Initializes the Flash interface and the Systick. */
  HAL_Init();

  /* Configure the system clock */
  SystemClock_Config();

  /* Initialize all configured peripherals */
  MX_GPIO_Init();
  MX_USART2_UART_Init();
  /* USER CODE BEGIN 2 */
  /* DBG_STOP is left clear. The 10 s window below is what makes SWD attach work. */
  /* NEVER TOUCH: must run after GPIO, before RTC/Stop. See function banner. */
  never_remove_swd_boot_window();
  MX_RTC_Init();
#ifdef BOARD_TEST
  /* Stays in Run. The plant image is what enters Stop. */
  board_test_run();
#else
  app_init();
#endif
  /* USER CODE END 2 */

  /* Infinite loop */
  /* USER CODE BEGIN WHILE */
  while (1)
  {
    /* USER CODE END WHILE */

    /* USER CODE BEGIN 3 */
#ifndef BOARD_TEST
    app_process();
    enter_stop();
#endif
  }
  /* USER CODE END 3 */
}

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


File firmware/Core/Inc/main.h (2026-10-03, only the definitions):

#define RED_Pin GPIO_PIN_2
#define RED_GPIO_Port GPIOA
#define GREEN_Pin GPIO_PIN_5
#define GREEN_GPIO_Port GPIOA
#define BUTTON_1_Pin GPIO_PIN_6
#define BUTTON_1_GPIO_Port GPIOA
#define BUTTON_2_Pin GPIO_PIN_7
#define BUTTON_2_GPIO_Port GPIOA

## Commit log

2026-10-03 Publish the rev B water timer so the hardware, firmware, and enclosure can be built from one place.
    [BOM-water_timer_revB.csv, case_back.step, case_back.stl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]
2026-10-03 Add a PDF of the schematic so it can be read without opening KiCad.
2026-10-03 Put the schematic PDF next to the KiCad project and link it from there.

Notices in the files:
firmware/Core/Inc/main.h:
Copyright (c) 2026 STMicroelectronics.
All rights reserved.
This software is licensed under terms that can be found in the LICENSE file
